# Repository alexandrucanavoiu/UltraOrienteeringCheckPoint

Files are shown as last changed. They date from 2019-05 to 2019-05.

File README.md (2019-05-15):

# Ultra Orienteering Check Point

Ultra Orienteering Check Point is based on OTIMCON and it is adapted to work with Ultra Orienteering Software

The system consists of controls (stations) which have RFID readers/writers, while the competitors wear RFID chips.

### Description
Hardware consists of:
1. Arduino Nano Atmega328P 16MHz 5V  ( <a href="https://www.ultra-orienteering.drumetiimontane.ro/download/imagini/arduino-nano.jpg">see the image</a> )
2. RFID RC522 ( <a href="https://www.ultra-orienteering.drumetiimontane.ro/download/imagini/rfid-rc522.jpg">see the image</a>  )
3. RTC DS3231 AT24C32 ( + battery CR2032 ) ( <a href="https://www.ultra-orienteering.drumetiimontane.ro/download/imagini/rtc-ds3231-at24c32.jpg">see the image</a> )
4. Active Buzzer 5V ( <a href="https://www.ultra-orienteering.drumetiimontane.ro/download/imagini/active-buzzer.jpg">see the image</a> )
5. RGB LED, common cathode, 5mm, 4pin ( <a href="https://www.ultra-orienteering.drumetiimontane.ro/download/imagini/rgb-led.jpg">see the image</a> )
6. DC-DC Boost Step-up 1-5V to 5V ( <a href="https://www.ultra-orienteering.drumetiimontane.ro/download/imagini/dc-dc-boost.jpg">see the image</a> )
7. Battery holders 3xAA ( <a href="https://www.ultra-orienteering.drumetiimontane.ro/download/imagini/suport_beterii.jpg">see the image</a> )
8. Box 100*68*50 ( <a href="https://www.ultra-orienteering.drumetiimontane.ro/download/imagini/carcasa.jpg">see the image</a> )
9. Proximity silicone bracelet with metallic buckle, with MIFARE chip (13.56MHz) ( <a href="https://www.ultra-orienteering.drumetiimontane.ro/download/imagini/suport.jpg">see the image</a> )
10. Support for components (made at 3d printer) ( <a href="https://www.ultra-orienteering.drumetiimontane.ro/download/imagini/arduino-nano.jpg">see the image</a> )
11. Cables AWG 24

It is loosely based on popular orienteering systems, and it's best used for orienteering, trekking, and other sports in which timing on several controls are needed.

This is done as the price of RFID modules went down, good RTC is easy to find, and microcontroller is just a glue. It's open so other makers can upgrade the system, or add additional modules like communication over WiFi / Bluetooth, a small screen with information, build a permanent course where the board is powered over solar cells etc.

### Check Point Scheme



### How to compile
1. Install Arduino IDE from https://www.arduino.cc/en/Main/Software
2. Install the drivers CH341SER for Arduino from Requirements\CH341SER\CH341SER\SETUP.exe
3. Copy the Libraries from Requirements\Libraries to your Documents\Ardiuno folder
4. Open src/otimcon0_2/optimcon0_2.io
5. From Tools select Board: Arduino Nano; Port: select the COM port; verify the code and Upload it.

### How to configure the Check Points
To configure these Check Points you use Orientare.exe from CheckPointSoftware\Orientare\bin\Release

##### 1. The Master Point
This station is used to download the data from Clocks (UUID CARDS).

Open Orientare.exe and configure your station with MODE > READOUT and press SET to apply. (<a href="https://www.ultra-orienteering.drumetiimontane.ro/images/master-checkpoint.png">see the image</a>)

Remember to select where you want to Save the files on your computer using "File" button or the software will stop running.

##### 2. Clear Check Point
This station is used to clear all data from the Clock (UUID CARDS).
* Open Orientare.exe and configure your station with MODE > CLEAR and press SET to apply. (<a href="https://www.ultra-orienteering.drumetiimontane.ro/images/clear-checkpoint.png">see the image</a>)

##### 3. Start Check Point
The code for Start Check Point is: 251

* Open Orientare.exe and configure your station with: MODE > CONTROL and press SET to apply and in the CTRL Field insert: 251 after that press SET. (<a href="https://www.ultra-orienteering.drumetiimontane.ro/images/start-checkpoint.png">see the image</a>)

##### 3. Finish Check Point

The code for Finish Check Point is: 252

* Open Orientare.exe and configure your station with: MODE > CONTROL and press SET to apply and in the CTRL Field insert: 252 after that press SET. (<a href="https://www.ultra-orienteering.drumetiimontane.ro/images/finish-checkpoint.png">see the image</a>)

##### 4. Intermediare Check Points
These station can have the CTRL with any integer number like "223" or "10".

* Open Orientare.exe and configure your station with: MODE > CONTROL and press SET to apply and in the CTRL Field insert: 223 after that press SET. (<a href="https://www.ultra-orienteering.drumetiimontane.ro/images/check-point.png">see the image</a>)

* You need to repeat these steps for each Check Point (station).

### Usage of the system
1. before start a CLEAR control (station) is used to clear out the card and prepare it
2. on start an additional station can be used (with control ID 251). On mass start a prewritten control with time can be added (WRITE CONTROL command), or a control with frozen time (FROZEN_CONTROL) can be used.
3. on the racetrack the competitors touch the RFID card by the control, where each control has its unique id (from 1 to 250)
4. on the finish the competitors touch against the finish control (ID 252).
5. after the finish the station in READOUT mode is used to read the timing on each control.

Before step 1. an administrator can reset the backup memory of each control so the memory of which cards passed can be saved.

### Usage of the station
Stations support serial communication (38400 8 N 1). All configuration is done through serial terminal. Use "?" for help.
_Note_ : use Arduino serial monitor for communication or a system that sends _newline_ at the end of the line, as most systems don't.
_Note_ : baud rate of 38400 is used. On some Arduino boards such speed isn't supported and it needs to be slowed - suggested speed is 9600.

### Serial commands
* __SET__
	* TIME YYYYMMDDhhmmss : Set time in year[Y], month[M], day[D], hour[h], minute[m], second[s] format  (eg. 20160817120024 is 2016/08/17 12:00:24)
	* CTRL number         : Set control ID as number (1-250), with special codes for START and FINISH stations (special id number defined in code)
	* MODE type           : Set modes (possible modes are CLEAR, CONTROL, CONTROL_WITH_READOUT, FROZEN_CONTROL, FULL_READOUT, PRINT, READOUT, WRITER)
	* RESET_BACKUP        : Reset pointer to 0th location on external EEPROM backup memory. In reality not neccessary as it rolls over, but nice to have a clean start.

* __GET__
	* TIME                : Get time in format YYYY/MM/DD hh:mm:ss - year[Y], month[M], day[D], hour[h], minute[m], second[s] eg. 2019/05/12 12:00:00
	* CTRL                : Get control ID as number (1-250 for normal controls, special codes for START and FINISH)
	* MODE                : Get mode status (CLEAR, CONTROL, CONTROL_WITH_READOUT, FROZEN_CONTROL, FULL_READOUT, PRINT, READOUT, WRITER)
	* BACKUP              : Get backup of whole external EEPROM (backup) memory. It returns all locations, even those which are not used.
	* VERSION             : Get current firmware version
	* VOLTAGE             : Get current battery voltage if the battery is connected to analog port 2. (may not work as expected)

  * __WRITE__   
  	* INFO  Any_text             : Write any text up to 30 characters which will be used in PRINT command as a CARD owner/user
  	* CTRL number YYYYMMDDhhmmss : Writes a control at the end of current controls. Useful to add a finish time in case of error, or to setup some controls (eg. START) prior to race.
  _Note_ : WRITE commands work only in WRITER mode.

  * __PING__
    * command PING will respond with PONG. It should be used as a keep awake system.

### Questions:
* What are CLEAR, CONTROL, CONTROL_WITH_READOUT, FROZEN_CONTROL, READOUT, FULL_READOUT and PRINT controls?
	* CONTROL is a normal station which saves data to RFID card, and sends (via serial) the UID of the card, timestamp in UNIX epoch format and a readable time.
  * CLEAR completely erases all the data on the RFID card.
  * READOUT reads every written control on the RFID card, from the first written to the last written on the card, and sends it via serial. It should be used with software on a computer.
  * CONTROL_WITH_READOUT does the same as control, but additionaly reads every previous control off the card. This is usable if some of the controls in the middle of the race are connected over Internet. Also it's usable to have one control for FINAL + automatic readout
  * FULL_READOUT is used when all 125 places on the card want to be read.
  * FROZEN_CONTROL is a station which has it's clock stopped. So every competitor will have the same time on that control. It's function is primarily for races with mass start (all competitors start at the same time), so the organizers do not need to set that into the software.
  * PRINT is a station which will nicely format and calculate the results of the station on the card, and send it via serial. It also prints the name of the user/owner of the card. It doesn't need the software on a computer.
_Note_ : There is a WRITER mode, but in that mode a command is to be given to a station prior of putting a card next to the RFID reader.

* How many controls can one RFID card accommodate?
	* Short answer: 125
	* Long answer: The system is prepared for MiFare 1K cards, which have 64 blocks (divided in 16 sectors) of 16 bytes. Each sector has 3 usable blocks, and one trailer block which has special meaning. First sector (blocks 0 - 3)is also off the limits. Second sector is prepared for info block (block 4) while blocks 5 and 6 are left free for anything (eg. competitor names). Data starts at block 8. Out of 56 blocks, there are 14 trailer blocks which are unusable, so control data can come to 42 blocks. Data about the control is saved in 5 bytes: 1 byte is control ID (number between 0-255), and 4 bytes is UNIX timestamp of the coming to control. So there are 3 controls per block - in total 42 x 3 = 126. There is a hard limit in code to 125.
	* For an visual answer look at the Documentation/CardAllocationOTIMCON.ods

* Is data safe on RFID card?
	* Data retention of the RFID memory is 10 years, or 200000 writes. So it's OK for a normal use. Additionaly, every block on the card has an additional CRC8 check on the end, so the data is written as it should.

* For what is BACKUP used?
	* If there is support for external EEPROM, then after writing data about the control onto the RFID chip, there is an additional write to external EEPROM with UID of the RFID card and timestamp.

* How big is BACKUP?
	* Backup saves last 512 cards (one card can be more than once, for those who forget to erase).

* What is info block in the RFID card?
	* Info block is block 4, where the last location is saved, last control and time of the last control.

* It looks like the serial port isn't working?
	* Make sure you're using a serial terminal which sends \n newline (most of the terminal software doesn't). Serial monitor in Arduino IDE works nicely.
	* Also make sure you're not using LOW POWER mode - in that case use an RFID card on the station prior to serial communication (see next question).

  * My station worked fine when I turned it on, but after an hour they are dead?
    * Check that LOW_POWER option is not active, and that HIGH_POWER is active.
    * If LOW_POWER is option is active, then each station goes through three states of work which are AWAKE -> SHALLOW SLEEP -> DEEP SLEEP.
      The station has to be in AWAKE mode for normal function (read/write), and the system is working at full speed.
      If no card or no serial command is present for 5 seconds, the station goes into SHALLOW SLEEP. In that mode station checks for card or serial command once every 250ms. If a card or serial command is present, it goes into AWAKE state.
      If no card or serial command is present in an hour of work in SHALLOW SLEEP, the station goes into DEEP SLEEP. In DEEP SLEEP the card or serial command is checked once every 2 seconds. Due to other electronics which needs to wake up, it can be up to 10 seconds needed for a control to fully wake up into AWAKE state. Just be patient.
      Time of 5 seconds used in AWAKE is chosen to not slow runners which came in bursts (several runners at once). Station can be forced in AWAKE state if any of the serial command is issued - PING can be used for keep AWAKE (or use HIGH_POWER option).
      The time of SHALLOW SLEEP of 250ms is not noticeable to runners. It can be lowered if needed.

* How can you use a MRFC522 on 5V?
	* MRFC522 is powered on 3.3V, and it will burn if you try to power it on 5V. But it seems that it can live with 5V on it's SPI port. The schematic given is my test bed, and all the orhers are done on a 3.3V Pro mini. DS3231 can work on either 3.3V or 5V, so it doesn't matter to it, this is just for the MRFC522.

* I did a RESET_BACKUP function but old data is still present in backup?
	* RESET_BACKUP just resets the internal counter back to 0 (first position), and starts overwriting from there. Nothing to be alarmed, it's like that by design.

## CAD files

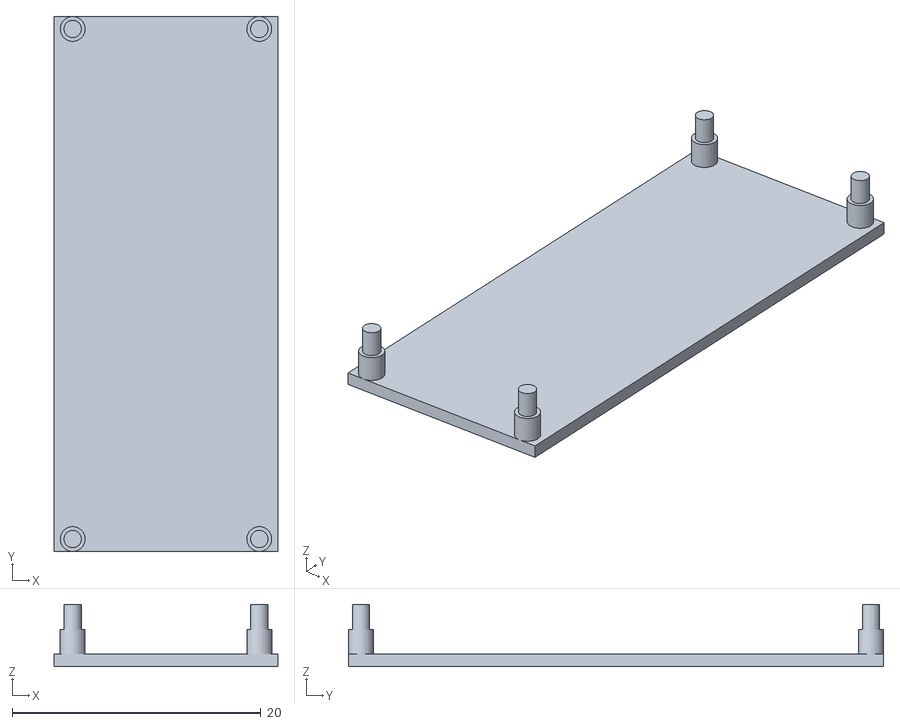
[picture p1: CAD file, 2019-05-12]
3D_Support_for_components/nano v2.2.stl
18.0 x 43.0 x 5.00

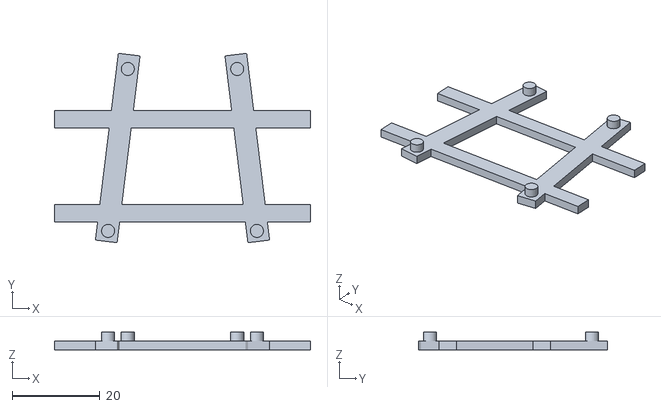
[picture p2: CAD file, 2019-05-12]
3D_Support_for_components/rc522_v2.0.stl
58.5 x 43.3 x 4.00

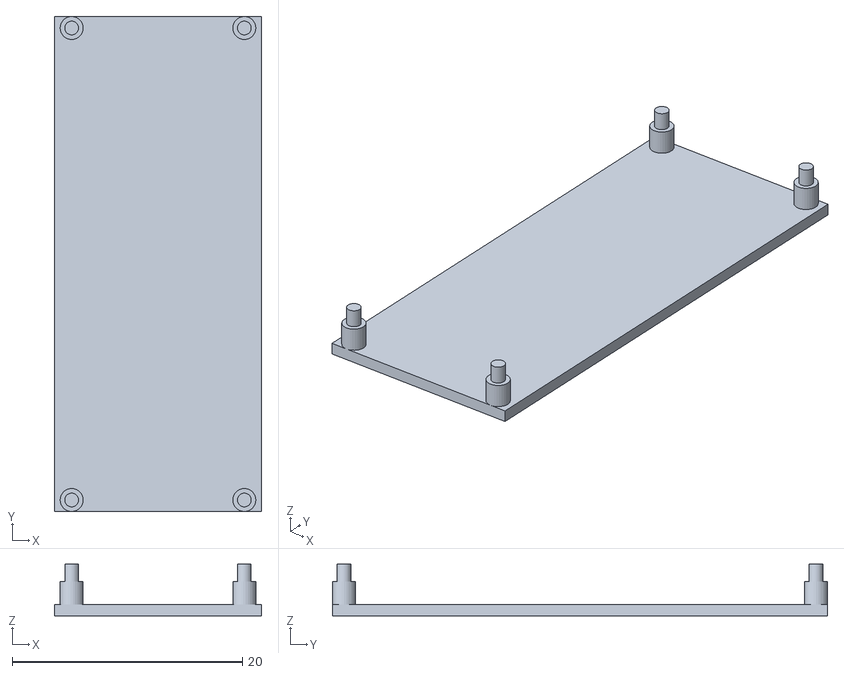
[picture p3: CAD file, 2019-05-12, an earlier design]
3D_Support_for_components/nano_v2.0.stl
18.0 x 43.0 x 4.50

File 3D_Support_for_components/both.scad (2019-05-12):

//translate([0,6,0]) nano();
 //rc522();
nano();

module nano() {
    translate([0,0,0.5]) cube([18,43,1], true);

a  = 7.5;
b  = 20.5;
r = 0.7;
translate([a,b,0])
    cylinder(5,r,r,false, $fn=30);

translate([-a,-b,0])
    cylinder(5,r,r,false, $fn=30);

translate([-a,b,0])
    cylinder(5,r,r,false, $fn=30);

translate([a,-b,0])
    cylinder(5,r,r,false, $fn=30);

translate([a,b,0])
    cylinder(3,1,1,false, $fn=30);

translate([-a,-b,0])
    cylinder(3,1,1,false, $fn=30);

translate([-a,b,0])
    cylinder(3,1,1,false, $fn=30);

translate([a,-b,0])
    cylinder(3,1,1,false, $fn=30);
}

module rc522() {
    translate([17,0,0])
    cylinder(4,1.5,1.5,false, $fn=30);
    
translate([-17,0,0])
    cylinder(4,1.5,1.5,false, $fn=30);
    
translate([12.5,37,0])
    cylinder(4,1.5,1.5,false, $fn=30);    
    
translate([-12.5,37,0])
    cylinder(4,1.5,1.5,false, $fn=30);    
    
rotate([0,0,-7]) translate([-17,17,1])    
    cube([5,43,2],true);
rotate([0,0,7])  translate([17,17,1])  
    cube([5,43,2],true);
    
//translate([-15,25,0])       cube([5,15,2],false);
//translate([10,25,0])  cube([5,15,2],false);
    
translate([0,25.5,1])   
    cube([58.5,4,2],true);

translate([0,4,1])   
    cube([58.5,4,2],true);

//translate([0,6,0.4]) cube([18,43,.8], true);
}

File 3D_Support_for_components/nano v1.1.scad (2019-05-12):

translate([0,0,0.5]) cube([17.5,43,1], true);

a  = 7.5;
b  = 20.5;
translate([a,b,0])
    cylinder(5,0.55,0.5,false, $fn=30);

translate([-a,-b,0])
    cylinder(5,0.55,0.5,false, $fn=30);

translate([-a,b,0])
    cylinder(5,0.55,0.5,false, $fn=30);

translate([a,-b,0])
    cylinder(5,0.55,0.5,false, $fn=30);

translate([a,b,0])
    cylinder(3,1,1,false, $fn=30);

translate([-a,-b,0])
    cylinder(3,1,1,false, $fn=30);

translate([-a,b,0])
    cylinder(3,1,1,false, $fn=30);

translate([a,-b,0])
    cylinder(3,1,1,false, $fn=30);

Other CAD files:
3D_Support_for_components/nano v2.1.stl

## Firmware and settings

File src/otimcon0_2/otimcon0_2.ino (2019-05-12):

#define SW_VERSION "0.22"
/*
 *************************************************************
 *  Project: Open Timing Control (OTIMCON)
 *  Version: 0.21 
 *  Date: 20180331
 *  Created by: Stipe Predanic (stipe.predanic (at) gmail.com)
 **************************************************************
 *
 * Required:
 *  HW:
 *  - Arduino based board (tested with Arduino Uno - AtMega328 board, should work on other Arduino systems if they support I2C and SPI)
 *     - NOTE: from version 0.2 string comparing is done against the PROGMEM, which isn't supported in other Arduino systems!  
 *             In that cse change the CMP_STRINGS macro.
 *  - MRFC522 module http://playground.arduino.cc/Learning/MFRC522
 *  - RTC clock supported by RTCLib (eg. DS1307, RTC_PCF8523, RTC_DS3231)
 *  - EEPROM (optional - used for backup, comes with DS3231 on popular cheap Chinese modules) 
 *  - LED (optional, depending on the way to give feedback)
 *  - piezo buzzer (optional, depending on the way to give feedback)
 * 
 *  SW:
 *  - Arduino IDE on a host computer 
 *  - Arduino libraries:
 *    + MFRC522 (download from http://makecourse.weebly.com/week10segment1.html , others may work e.g. the one in Arduino IDE)
 *    + RTCLib (any version, AdaFruit version is available in Arduino IDE )
 *    + SerialCommand Library ( https://github.com/kiwisincebirth/Arduino-SerialCommand )
 *    + Low-Power Library by RocketScream (available in Arduino IDE)
 *    + PinChangeInterrupt by NicoHood (available in Arduino IDE)
 *
 **************************************************************
 *
 * HW connection (if used by 328 type board)
 *  - DS3231 module connected via I2C on A4 (SDA) and A5 (SCL)  
 *  - MFRC522 conected via SPI (D13 SCK, D12 MISO, D11 MOSI, with RESET AND SS are selected in code (in this case SS is D10, and RESET D9)
 *  - LED and or piezo are connected to pin selected in code (in this case LED is on D8 and PIEZO on D7). 
 *  
 *  Don't forget the resistors for current (LED, piezo) or for pull-up and pull-down on SPI/I2C
 *
 **************************************************************
 *
 * See documentation/CHANGELOG for history of OTIMCON
 * 
 **************************************************************
*/


#include <SPI.h>          //include the SPI bus library
#include <MFRC522.h>      //include the RFID reader library
#include <Wire.h>
#include <RTClib.h>       // include timer library 
#include <SerialCommand.h>  // include serial command system
#include <EEPROM.h>
#include "LowPower.h"


#define SERIAL_BAUD 38400

// used for debugging purposes. Should be commented out in production or set to 0. Higher number, more information
#define DEBUG 0


// comment these if you don't have them, so the code will be smaller
// preprocessing command are used!
#define USE_EEPROM_BACKUP
#define USE_LED
#define USE_PIEZO

// comment this if you want to use serial only if neccessary. If this is uncommented it will always use serial port, even if nothing is connected.
#define USE_SERIAL_ALWAYS  
                     
// comment this if you don't need low power work (the system won't go to sleep but serial will always work)
//#define LOW_POWER  

// uncomment this if you want to use a little more energy - needed when powered from cheep powerbanks which auto shut off.
// The control will not go to sleep, and will blink a LED on HIGH_POWER_LED (by default pin 4, can be changed)
#define HIGH_POWER  


#define DS3231_I2C_ADDRESS 0x68    // I2C address for DS3231
#define EEEPROM_I2C_ADDRESS 0x57   // default I2C address for EEPROM on DS3231 modules


#define SS_PIN             10                 //slave select pin for SPI (used by MFRC522)
#define RST_PIN             9                 //reset pin

#define FEEDBACK_LED        8                 // pin for LED
#define FEEDBACK_PIEZO      7                 // piezo

#define SERIAL_ACTIVE_PIN   6                // if you want to use serial only when needed, then select a pin (this is D6) and connect it HIGH 

#define RTC_POWER_PIN       5                // power RTC only when needed, from this pin. Can be changed
#define RTC_POWER_ON        1
#define RTC_POWER_OFF       0

#define HIGH_POWER_LED      8                // will blink when HIGH_POWER is used, as an additional power usage, when cheap powerbanks with auto shut off are used.
#define HIGH_POWER_LED_PERCENTAGE 5          // define, in percentage of a block time of around 10 seconds, how long should a LED be turned on. The bigger the number, the longer LED stays on, the bigger is consumption. Cannot be over 100. 
#define LAST_TIME_FROM_WRITING 30            // number of seconds between two consecutive writes if the same card user comes to the station (from now on called control)
#define PRINT_END_LINE      4                // used in mode PRINT, number of empty lines after the text "Timing by OTIMCON", used to cut the paper off the POS printer

#define ANALOG_REFERENCE  EXTERNAL
//#define VOLTAGE_REFERENCE 2                   // used for measuring the voltage, easier to code if 5V is used (error is 2.4%). It will output 512 for 5V.
#define VOLTAGE_REFERENCE 1024. / 500       // used for measuring the voltage, voltage will be as fixed point arithmetic (100 = 1V)  500 = 5V


//#define VOLTAGE_REFERENCE 3                 // used for measuring the voltage, easier to code if 3.3V is used (error is around 3.3%)
//#define VOLTAGE_REFERENCE 1024. / 330       // used for measuring the voltage, voltage will be as fixed point arithmetic (100 = 1V)  330 = 3.3V


// using internal refence for ADC is suggested but it needs to be done right. So by default this is not done!
//#define ANALOG_REFERENCE  INTERNAL
//#define VOLTAGE_REFERENCE 9                 // used for measuring the voltage, easier to code if 1.1V internal reference is used (error is around 3.4%)
//#define VOLTAGE_REFERENCE 1024. / 110       // used for measuring the voltage, voltage will be as fixed point arithmetic (100 = 1V)  330 = 1.1V



// define ID's for START and FINISH controls. as 1-250 are for controls, available numbers are 253-255 and 0
#define START_CONTROL_ID 251
#define FINISH_CONTROL_ID 252


// define the function of the control
// should convert to enum but I like it this way
#define CLEAR                1                  // works as a clear, and prepares a card for OTIMCON
#define CONTROL              2                  // works as a standard control with id
#define CONTROL_WITH_READOUT 3                  // works as a control which has a readout of all controls in the card
#define READOUT              4                  // works as a readout only of all controls in the card
#define FULL_READOUT         5                  // works as a readout only for the whole card
#define PRINT                6                  // works as a printout, calculates time
#define WRITER               7                  // works as a specialty writer for additional data into cards, and to write controls if needed
#define FROZEN_CONTROL       8                  // works as a control with id, but with time frozen 


#define EEPROM_ADDRESS_MODE       10  // address in EEPROM for saving mode
#define EEPROM_ADDRESS_CONTROL_ID 11  // address in EEPROM for saving control ID  


#define EEPROM_ADDRESS_FROZENTIME 12  // address where the frozen time will be saved, if the mode frozen control is used. Note, it will use 4 bytes!
#define EEPROM_ADDRESS_OPTIONS    16  // different options stored - for POS printers, and time freeze


// change this from time to time for wear leveling, as write is done after _every card_
#define EEPROM_ADDRESS_24C32_LOCATION 20  // location of high part of address in external EEPROM for saving backup of used cards   

#define EXTERNAL_EEPROM_SIZE       4096  // maximum number of bytes in external EEPROM 


// a special code found on byte 0 of block 4, which detects that card is prepared for OTIMCON.
// THIS constant _MUST_ be the _SAME_ at all OTIMCON controls in one competition! 
// This is a security if other cards (non-race cards) are put at the OTIMCON control.
// !! Nothing will be written if card is not prepared by touching the CLEAR control.!!
// !! DON'T TOUCH UNLESS YOU KNOW WHAT YOU ARE DOING !!
#define OTIMCON_CARD_TYPE      0xAD      


static RTC_DS3231 rtc;
static MFRC522 mfrc522(SS_PIN, RST_PIN);        // instatiate a MFRC522 reader object.
static MFRC522::MIFARE_Key key;                 //create a MIFARE_Key struct named 'key', which will hold the card information

static byte controlId;                         // current ID of this station (from now on called control)    
static byte readbackblock[18];                 //This array is used for reading out a block. The MIFARE_Read method requires a buffer that is at least 18 bytes to hold the 16 bytes of a block.
static long currentTime;                       // currentTime, used for saving the time from RTC (without the need of continuos read in functions).


// I know this is very wasteful, but it's easier for anyone who wants to change the code
static boolean useSerial = true;
static boolean cardPresent = false;
static boolean writerCardPresent = false;

static boolean printEscPos = false;        // used in mode PRINT, use EPSON ECS/POS format or not. Set to true if connected directly to POS printer, false if viewed on a serial monitor

static boolean timeToBleep;                // the boolean which starts the bleeping (LED & PIEZO activation)

static byte writerData[30]={0};
static byte writerJob;     

byte controlFunction;

#ifdef USE_EEPROM_BACKUP
static short int locationOnExternalEEPROM = 0;
#endif


static unsigned short deepSleepCounter;
static unsigned short shallowSleepCounter;
static unsigned short wakePowerBankCounter;

static SerialCommand  sCmd   = SerialCommand();       // The demo SerialCommand object
static CommandHandler sHand1 = CommandHandler(sCmd);  // the main command handler
static CommandHandler sHand2 = CommandHandler(sCmd);  // the sub command handler for SET command
static CommandHandler sHand3 = CommandHandler(sCmd);  // the sub command handler for GET command
static CommandHandler sHand4 = CommandHandler(sCmd);  // the sub command handler for WRITE command


/**
 * setup function of the Arduino toolchain
 * 
 */
void setup() {
      pinMode(RTC_POWER_PIN, OUTPUT); // set pin for output, as RTC and EEPROM will get power from microcontroller
      powerToRTC(RTC_POWER_ON);
      
      Serial.begin(SERIAL_BAUD);        // Initialize serial communications with the PC
      SPI.begin();               // Init SPI bus

      mfrc522.PCD_Init();        // Init MFRC522 card (in case you wonder what PCD means: proximity coupling device)
      
     
      Serial.println(F("Starting..."));     
      // if RTC cannot be started, then there is no RTC.
      if (! rtc.begin()) {
        Serial.println(F("No RTC"));
        while (1);   // sketch halts in an endless loop
      }

      // if RTC is running, check the time. If the time in the chip is in the past, then it's set the same as computer clock 
      // warning: it will reset back to uploading time, if there is no backup battery on DS3231
      DateTime now = rtc.now();
      DateTime compiled = DateTime(F(__DATE__), F(__TIME__));
      
      if (now.unixtime() < compiled.unixtime() ) {
        rtc.adjust(DateTime(F(__DATE__), F(__TIME__)));
      }

        
        controlId = EEPROM.read(EEPROM_ADDRESS_CONTROL_ID);              // set ID of the control station. Any number between 1-250. Beware: it can be anything if new Arduino is used.
         
        controlFunction = EEPROM.read(EEPROM_ADDRESS_MODE);              // set function (mode) of control. Beware: it can be anything if new Arduino is used. 
        if (controlFunction > WRITER || controlFunction == 0) controlFunction = READOUT;  // if controlFunction is something crazy (eg. new Arduino), set it to READOUT.

        printEscPos =  ((EEPROM.read(EEPROM_ADDRESS_OPTIONS) & 0x1) > 0) ? true : false;  // set the Epson POS standard or not in PRINT mode
        if (controlFunction == FROZEN_CONTROL) {
            currentTime = EEPROM.get(EEPROM_ADDRESS_FROZENTIME, currentTime);  // sets the time for usage if frozen control is used
        }
        writerJob = 0; 
           

#ifdef USE_EEPROM_BACKUP        
       EEPROM.get(EEPROM_ADDRESS_24C32_LOCATION, locationOnExternalEEPROM);
#endif
       
       // define pin modes for LED and PIEZO, if they are used
#ifdef USE_LED
       pinMode(FEEDBACK_LED, OUTPUT);
#endif
#ifdef USE_PIEZO
       pinMode(FEEDBACK_PIEZO, OUTPUT);
#endif

      // if USE_SERIAL_ALWAYS is not set, then it's needed to set a pin SERIAL_ACTIVE_PIN
#ifndef USE_SERIAL_ALWAYS
       pinMode(SERIAL_ACTIVE_PIN, INPUT);
#endif

      powerToRTC(RTC_POWER_OFF);
      
        
      
        // Prepare the security key for the read and write functions - all six key bytes are set to 0xFF at chip delivery from the factory.
        // Since the cards in the kit are new and the keys were never defined, they are 0xFF
        // if we had a card that was programmed by someone else, we would need to know the key to be able to access it. This key would then need to be stored in 'key' instead.
        
        // NOTICE: If you want to block reading and writing cards by somebody else, change block3 of each sector on a card and then change this lines to something else.
        for (byte i = 0; i < 6; i++) {
                key.keyByte[i] = 0xFF;//keyByte is defined in the "MIFARE_Key" 'struct' definition in the .h file of the library
        }

/****
*/
#if ANALOG_REFERENCE == INTERNAL
        // uncomment this if you want to use internal analog reference of 1.1V
        // BE CAREFUL WITH SETTING THE INPUT.
        // analogReference(INTERNAL);
#endif
/*
****** */

  // set the main handler for serial command
  sCmd.setHandler(sHand1);

  // Setup callbacks for the main SerialCommand. These are the main commands
  sHand1.addHandler("SET",    sHand2);          // Handler for everything starting with SET
  sHand1.addHandler("GET",    sHand3);          // Handler for everything starting with GET
  sHand1.addHandler("WRITE",  sHand4);          // Handler for everything starting with WRITE
  sHand1.addCommand("PING",   s_pong);          // Handler for PING keepalive messages
  sHand1.addCommand("BLEEP",   bleep);           // Handler for BLEEP
  sHand1.addCommand("?",      s_help);            // Handler for help 
  sHand1.setDefault(          s_unrecognized);    // Handler for command that isn't matched  (says "What?")

  
  // Setup the commands the SET
  sHand2.addCommand("TIME",  s_setTime);         // Set time
  sHand2.addCommand("CTRL",  s_setControl);      // Set control number
  sHand2.addCommand("MODE",  s_setMode);         // Set mode
  sHand2.addCommand("RESET_BACKUP",   s_setResetBackup); // reset backup memory pointer to 0
  sHand2.setDefault(         s_unrecognized);    // Handler for command that isn't matched  (says "What?")
  
  sHand3.addCommand("TIME",  s_getTime);         // Get current time
  sHand3.addCommand("CTRL",  s_getControl);      // Get current control number
  sHand3.addCommand("MODE",  s_getMode);         // Get current mode
  sHand3.addCommand("VOLTAGE",  s_getVoltage);   // Get battery voltage
  sHand3.addCommand("VERSION",  s_getVersion);   // Get current firmware version
  sHand3.addCommand("BACKUP",  s_getBackup);     // Get current memory backup in external EEPROM
  sHand3.setDefault(         s_unrecognized);    // Handler for command that isn't matched  (says "What?")

  sHand4.addCommand("INFO",  s_writeInfo);         // Write info1 on the card
  sHand4.addCommand("CONTROL",  s_writeControl);     // Writes arbritary control to the next position
 




#if DEBUG > 0
  Serial.println(F("Setup finished!"));
#endif  
  Serial.print(F(">"));

  shallowSleepCounter = 0;
  deepSleepCounter = 0;
  wakePowerBankCounter = 0;
}


void loop()
{
  static byte oldRFIDCardUid[4]; 
  static long lastBleepTime; 


#ifdef HIGH_POWER
      if (!timeToBleep) {
         wakePowerBankCounter++;

         // set this number to define how long the LED should blink.
         if (wakePowerBankCounter < HIGH_POWER_LED_PERCENTAGE)  {
            digitalWrite(HIGH_POWER_LED, HIGH);   
         }
         else if (wakePowerBankCounter > 100) {
                 wakePowerBankCounter = 0; 
              }
              else {
                 digitalWrite(HIGH_POWER_LED, LOW); 
              }
        } 
#endif          

      
        
               
/*** 
 *  check serial state - check the #define, by default is on pin D6
 */
#ifdef USE_SERIAL_ALWAYS
    useSerial = true;
#else
    useSerial = (HIGH == digitalRead(SERIAL_ACTIVE_PIN)) ? true : false ;
#endif
     
     
      
     // serial will work for about 15 seconds after the card is read (serial work reset the shallowSleepCounter),
     // but other times the system is just sleep <-> RFID
     if (shallowSleepCounter > 0x1FF) {
        //Serial.flush();
        sleep();
     } 
     
     // check serial, if there is something new on connected link
     if (useSerial) {
         sCmd.readSerial();     // We don't do much, just process serial commands
      }
     shallowSleepCounter++;    

// if LOW_POWER is commented out, then it it will never go to sleep and Serial will be apsolutly responsive.     
#ifndef LOW_POWER
      Serial.flush();
      shallowSleepCounter = 0;
#endif     
     
   
        /*****************************************establishing contact with a tag/card**********************************************************************/
  
  // should always fail, but needed to have the correct detection of new cards
  // Look for new cards (in case you wonder what PICC means: proximity integrated circuit card)
	if ( ! mfrc522.PICC_IsNewCardPresent()) {     //if PICC_IsNewCardPresent returns 1, a new card has been found and we continue
     return;                                     //if it did not find a new card is returns a '0' and we return to the start of the loop
	}
  else // Select one of the cards
	  if ( ! mfrc522.PICC_ReadCardSerial()) {       //if PICC_ReadCardSerial returns 1, the "uid" struct (see MFRC522.h lines 238-45)) contains the ID of the read card.
		  cardPresent = false;
      return;                                     //if it returns a '0' something went wrong and we return to the start of the loop
	  }

  
// If the code comes to here, then a card is found and selected!

// Sometimes new card is not recognized correctly:
// 1. check if it's the same card as it was before.
// 2. even if it's the same card, check the time difference, sometimes it's OK for a runner to revisit the control after a while. Don't use the RTC, use millis for fast check as 
// control shouldn't be in sleep for the last 2 seconds, there is additional check with RTC later on.
  if ( cardPresent ) {
    byte xorId = 0;
    for (byte i = 0; i < mfrc522.uid.size; i++) {
      xorId = xorId ^ mfrc522.uid.uidByte[i] ^ oldRFIDCardUid[i];  
    }
    // if different card, say false!
    if ( xorId ) {
      cardPresent = false;
    } // even if same card, if time is over a second, say false and recheck it later
    else if (millis() - lastBleepTime > 1000) {
      cardPresent = false;
    } else { // same card, long push
      cardPresent = true;
     
      // move the time so doesn't repeat in case of very long card push
      lastBleepTime = millis();
   }
 }
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

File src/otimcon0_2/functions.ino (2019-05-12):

/**
 * 
 * function which reads a block out of RFID card
 * 
 * Note: this readblock works only if number of blocks is under 256
 *
 * @param blockNumber  number of the wanted block
 * @param arrayAddress  end array in which the data from the block will be saved (length at least 16 bytes)
 * 
 * @return information about errors or success  
 *          1  success
 *          3  card authentication failed (trailer block keys are wrong)
 *          4  write failed 
 */

byte readBlock(byte blockNumber, byte arrayAddress[]) 
{
  int largestModulo4Number=blockNumber/4*4;
  int trailerBlock=largestModulo4Number+3;//determine trailer block for the sector

  /*****************************************authentication of the desired block for access***********************************************************/
  byte status = mfrc522.PCD_Authenticate(MFRC522::PICC_CMD_MF_AUTH_KEY_A, trailerBlock, &key, &(mfrc522.uid));
  //byte PCD_Authenticate(byte command, byte blockAddr, MIFARE_Key *key, Uid *uid);
  //this method is used to authenticate a certain block for writing or reading
  //command: See enumerations above -> PICC_CMD_MF_AUTH_KEY_A  = 0x60 (=1100000),    // this command performs authentication with Key A
  //blockAddr is the number of the block from 0 to 15.
  //MIFARE_Key *key is a pointer to the MIFARE_Key struct defined above, this struct needs to be defined for each block. New cards have all A/B= FF FF FF FF FF FF
  //Uid *uid is a pointer to the UID struct that contains the user ID of the card.
  if (status != MFRC522::STATUS_OK) {
#if DEBUG > 2   
         Serial.print(F("PCD_Authenticate() failed (read): "));
         Serial.println(mfrc522.GetStatusCodeName(status));
#endif         
         return 3;//return "3" as error message
  }
  //it appears the authentication needs to be made before every block read/write within a specific sector.
  //If a different sector is being authenticated access to the previous one is lost.


  /*****************************************reading a block***********************************************************/
        
  byte buffersize = 18;//we need to define a variable with the read buffer size, since the MIFARE_Read method below needs a pointer to the variable that contains the size... 
  status = mfrc522.MIFARE_Read(blockNumber, arrayAddress, &buffersize);//&buffersize is a pointer to the buffersize variable; MIFARE_Read requires a pointer instead of just a number
  if (status != MFRC522::STATUS_OK) {
#if DEBUG > 3 
          Serial.print(F("MIFARE_read() failed: "));
          Serial.println(mfrc522.GetStatusCodeName(status));
#endif         
          return 4;//return "4" as error message
  }
#if DEBUG > 3 
  Serial.println(F("block was read"));
#endif
  return 1;
}



/**
 * CRC-8
 * 
 * based on the CRC8 formulas by Dallas/Maxim
 * code released under the therms of the GNU GPL 3.0 license
 * 
 * @param data  array to calculate CRC
 * @param len   length of the array 
 * 
 * @return crc  CRC of the array
 */
byte CRC8(const byte *data, byte len) {
  byte crc = 0x00;
  while (len--) {
    byte extract = *data++;
    for (byte tempI = 8; tempI; tempI--) {
      byte sum = (crc ^ extract) & 0x01;
      crc >>= 1;
      if (sum) {
        crc ^= 0x8C;
      }
      extract >>= 1;
    }
  }
  return crc;
}


/**
 * write data about this control to a location on the card
 * 
 * 
 * @param location    where to write. should be a number in the range [0,125] 
 * @param id          id of the control
 * @param timestamp   timestamp to write to control
 */
boolean writeDataToLocation(byte location, byte id, long int timestamp) {

  byte writingInfo;                                  // used to get error value from the writeBlock function
  
  // convert timestamp to 4 separate bytes
  static byte timestampArray[4] = {0};
  
  timestampArray[0] = (byte) (timestamp & 0xFF);       // set the lowest 8 bits of timestamp
  timestampArray[1] = (byte) ((timestamp >> 8) & 0xFF);
  timestampArray[2] = (byte) ((timestamp >> 16) & 0xFF);
  timestampArray[3] = (byte) ((timestamp >> 24) & 0xFF);  // set the highest 8 bits of timestamp

  // if card is full (and somehow it got past the writeCurrentControl() then send serial info about it, and return 0 as write was not successfull.
  if (location > 125) { 
    if ( useSerial ) {
       Serial.println(F("Error: card full - "));
       Serial.print(id);
       Serial.print(F(","));
      serialPrintUid();
         
    }
    return 0;
  }
  // send data over serial only if serial is ON
    // DEBUG DATA FOR EASIER READING
#if DEBUG > 1    
      Serial.println(F("Writing location, id, timestamp"));
   // END DEBUG DATA
    Serial.print(location);
    Serial.print(F(","));
    Serial.print(id);
    Serial.print(F(","));
    Serial.println(timestamp);
#endif
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
